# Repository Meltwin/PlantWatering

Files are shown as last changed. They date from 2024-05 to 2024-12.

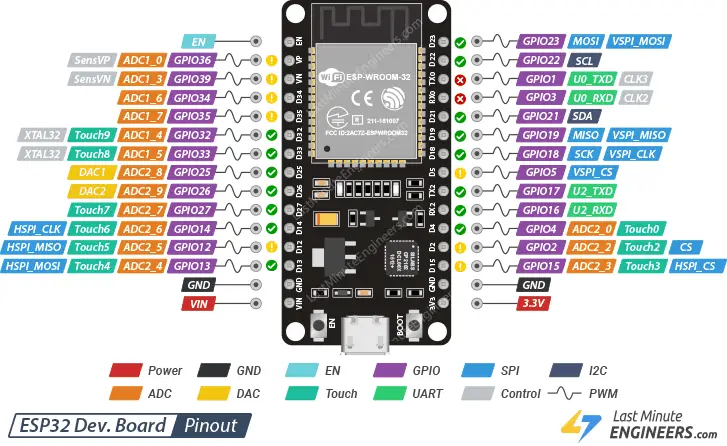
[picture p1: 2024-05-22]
img/esp-wroom-32-pinout.png

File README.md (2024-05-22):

<h1 align="center">
    Automatic plant watering system
</h1>

This project consist of making an automated watering system for my plants. It works with an ESP-32 board that controls a 5V pump. This repository contains:

- The electrical schematic (made in KiCAD) that can be found in the `KiCAD` folder,
- The code for the ESP-32 board in the `plant_watering` folder,

The project was tested and made on a ESP-WROOM-32 board.

Distributed under the MIT licence. Copyright (c) 2024 Meltwin

## Hardware description

The parts used here are:

- an ESP32 board,
- a dual MOFSET driver,
- USB-C female port for power input,
- Barrel Jack female port for power output (for the pump)

## Software description

The software available here control a 5V pump through the dual MOSFET driver with a PWM signal. There two main parameter for controlling the pump behaviour: the **opened time** and the **opened frequency**. This way people can freely choose the quantity of water to actually drop according to the type of plant.

This data will be stored onto the ESP controller internal storage so that it survive power disconnect.

## Online resources used

- [ESP-32 Getting Started - Expressif](https://docs.espressif.com/projects/esp-idf/en/stable/esp32/hw-reference/esp32/get-started-devkitc.html)
- [ESP-32 Pinout - Last Minute Engineers](https://lastminuteengineers.com/esp32-pinout-reference/)
- [PWN usage - Upesy (FR only)](https://www.upesy.fr/blogs/tutorials/how-to-use-pwm-on-esp32-with-examples)
- [ADC usage - Last Minute Engineers](https://lastminuteengineers.com/esp32-basics-adc/)

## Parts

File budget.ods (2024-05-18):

Item | N | Link | Price | N Units | Price / U |  | Option 1 (DE) |  |  | Option 2 (US) |  |  | Option 3 (DE + US) |  |  | Option 1
 |  |  |  |  |  |  |  |  |  |  |  |  |  |  |  | Total | Needed
5V Pump | 1 | Amazon DE (https://www.amazon.de/-/en/RUNCCI-YUN-Submersible-Aquarium-Watering-Flowers/dp/B08BZBN29C) | 9,44 € | 3 | 3,15 € | 1 | X | 3,15 € | 9,44 € |  | 0,00 € | 0,00 € |  | 0,00 € | 0,00 € | 63,80 € | 9,75 € | 15,29 %
5V Pump | 1 | Amazon DE (https://www.amazon.de/-/en/gp/product/B0B24G8WP7) | 8,39 € | 1 | 8,39 € | 1 |  | 0,00 € | 0,00 € |  | 0,00 € | 0,00 € |  | 0,00 € | 0,00 €
5V Pump | 1 | Amazon US (https://www.amazon.com/ALAMSCN-Submersible-Aquariums-Fountain-Hydroponics/dp/B08PBQ1N1G?rnid=2661617011) | $9,99 | 4 | $2,50 | 0,93 |  | 0,00 € | 0,00 € | X | 2,32 € | 9,29 € | X | 2,32 € | 9,29 €
Mosfet drivers | 1 | Amazon DE (https://www.amazon.de/-/en/Trigger-Setting-Electronic-Control-Arduino/dp/B0C3LXNK7T) | 11,99 € | 20 | 0,60 € | 1 | X | 0,60 € | 11,99 € |  | 0,00 € | 0,00 € |  | 0,00 € | 0,00 € | Option 2
H Bridge | 1 | Amazon DE (https://www.amazon.de/-/en/ARCELI-Pieces-Controller-Module-Arduino/dp/B07MY33PC9/) | 13,65 € | 5 | 2,73 € | 1 |  | 0,00 € | 0,00 € |  | 0,00 € | 0,00 € |  | 0,00 € | 0,00 € | Total | Needed
Mosfet drivers | 1 | Amazon US (https://www.amazon.com/XLX-Transistor-Module-PWM-Regulator-Electronic-Switch-Controller/dp/B07ZHC5M7H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) | $11,99 | 10 | $1,20 | 0,93 |  | 0,00 € | 0,00 € | X | 1,12 € | 11,15 € | X | 1,12 € | 11,15 € | 71,83 € | 8,69 € | 12,09 %
W Alu Heatsinks | 1 | Amazon DE (https://www.amazon.de/-/en/VooGenzek-Aluminium-Raspberry-Heatsink-Conducting/dp/B0C2HW56YJ?rnid=419116031) | 6,91 € | 40 | 0,17 € | 1 | X | 0,17 € | 6,91 € |  | 0,00 € | 0,00 € | X | 0,17 € | 6,91 €
Kit Alu Heatsinks | 1 | Amazon DE (https://www.amazon.de/-/en/Different-Heatsink-Conductive-Aluminium-Raspberry/dp/B099J1W63H) | 19,95 € | 102 | 0,20 € | 1 |  | 0,00 € | 0,00 € |  | 0,00 € | 0,00 € |  | 0,00 € | 0,00 € | Option 3
Kit Alu Heatsinks | 1 | Amazon US (https://www.amazon.com/GeeekPi-Conductive-Raspberry-Transistor-Regulator/dp/B099DTH24X) | $15,99 | 100 | $0,16 | 0,93 |  | 0,00 € | 0,00 € |  | 0,00 € | 0,00 € |  | 0,00 € | 0,00 € | Total | Needed
Kit Alu Heatsinks | 1 | Amazon US (https://www.amazon.com/Raspberry-Heatsink-Conductive-Adhesive-Aluminum/dp/B082RWXFR2) | $12,99 | 100 | $0,13 | 0,93 |  | 0,00 € | 0,00 € |  | 0,00 € | 0,00 € |  | 0,00 € | 0,00 € | 66,93 € | 8,76 € | 13,09 %
Kit Alu Heatsinks | 1 | Amazon US (https://www.amazon.com/Raspberry-Heatsink-MazerPi-Aluminum-Thermal/dp/B0963BMGFY) | $11,99 | 100 | $0,12 | 0,93 |  | 0,00 € | 0,00 € | X | 0,11 € | 11,15 € |  | 0,00 € | 0,00 €
Heatshrink tubes | 6 | Amazon DE (https://www.amazon.de/-/en/ASHINER-Heat-Shrink-Tube-Set/dp/B08XXGNJHG) | 10,49 € | 580 | 0,02 € | 1 | X | 0,11 € | 10,49 € |  | 0,00 € | 0,00 € |  | 0,00 € | 0,00 €
Heatshrink tubes | 6 | Amazon US (https://www.amazon.com/560PCS-Heat-Shrink-Tubing-Eventronic/dp/B072PCQ2LW) | $6,99 | 560 | $0,01 | 0,93 |  | 0,00 € | 0,00 € | X | 0,07 € | 6,50 € | X | 0,07 € | 6,50 € | EUR coef | 1 | EUR/EUR
ESP32 | 1 | Amazon US (https://www.amazon.com/DORHEA-Development-Bluetooth-ESP-WROOM-32-ESP32-DevKitC-32/dp/B0B18NK2MS) | $26,99 | 5 | $5,40 | 0,93 |  | 0,00 € | 0,00 € | X | 5,02 € | 25,10 € | X | 5,02 € | 25,10 € | USD coef | 0,93 | EUR/USD
ESP32 | 1 | Amazon DE (https://www.amazon.de/-/en/pieces-ESP32-development-NodeMCU-modules/dp/B0CF9HF3PG) | 16,99 € | 3 | 5,66 € | 1 | X | 5,66 € | 16,99 € |  | 0,00 € | 0,00 € |  | 0,00 € | 0,00 €
 |  |  | 0,00 € | 1 | 0,00 € | 1 |  | 0,00 € | 0,00 € |  | 0,00 € | 0,00 € |  | 0,00 € | 0,00 €
Self-Taping screws | 4 | Amazon US (https://www.amazon.com/HanTof-Phillips-Computer-Self-Tapping-Electronic/dp/B07ZH9GJWP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) | $9,29 | 750 | $0,01 | 0,93 |  | 0,00 € | 0,00 € | X | 0,05 € | 8,64 € |  | 0,00 € | 0,00 €
Self-Taping screws | 4 | Amazon DE (https://www.amazon.de/-/en/VooGenzek-Self-Tapping-Tapping-Phillips-Plastic/dp/B09NDPGJG1?rnid=419116031) | 7,98 € | 500 | 0,02 € | 1 | X | 0,06 € | 7,98 € |  | 0,00 € | 0,00 € | X | 0,06 € | 7,98 €
 |  |  | 0,00 € | 1 | 0,00 € | 1 |  | 0,00 € | 0,00 € |  | 0,00 € | 0,00 € |  | 0,00 € | 0,00 €
 |  |  | 0,00 € | 1 | 0,00 € | 1 |  | 0,00 € | 0,00 € |  | 0,00 € | 0,00 € |  | 0,00 € | 0,00 €
 |  |  | 0,00 € | 1 | 0,00 € | 1 |  | 0,00 € | 0,00 € |  | 0,00 € | 0,00 € |  | 0,00 € | 0,00 €
 |  |  | 0,00 € | 1 | 0,00 € | 1 |  | 0,00 € | 0,00 € |  | 0,00 € | 0,00 € |  | 0,00 € | 0,00 €
 |  |  | 0,00 € | 1 | 0,00 € | 1 |  | 0,00 € | 0,00 € |  | 0,00 € | 0,00 € |  | 0,00 € | 0,00 €
 |  |  | 0,00 € | 1 | 0,00 € | 1 |  | 0,00 € | 0,00 € |  | 0,00 € | 0,00 € |  | 0,00 € | 0,00 €
 |  |  | 0,00 € | 1 | 0,00 € | 1 |  | 0,00 € | 0,00 € |  | 0,00 € | 0,00 € |  | 0,00 € | 0,00 €
 |  |  | 0,00 € | 1 | 0,00 € | 1 |  | 0,00 € | 0,00 € |  | 0,00 € | 0,00 € |  | 0,00 € | 0,00 €
 |  |  | 0,00 € | 1 | 0,00 € | 1 |  | 0,00 € | 0,00 € |  | 0,00 € | 0,00 € |  | 0,00 € | 0,00 €
 |  |  | 0,00 € | 1 | 0,00 € | 1 |  | 0,00 € | 0,00 € |  | 0,00 € | 0,00 € |  | 0,00 € | 0,00 €
 |  |  | 0,00 € | 1 | 0,00 € | 1 |  | 0,00 € | 0,00 € |  | 0,00 € | 0,00 € |  | 0,00 € | 0,00 €
 |  |  | 0,00 € | 1 | 0,00 € | 1 |  | 0,00 € | 0,00 € |  | 0,00 € | 0,00 € |  | 0,00 € | 0,00 €
 |  |  | 0,00 € | 1 | 0,00 € | 1 |  | 0,00 € | 0,00 € |  | 0,00 € | 0,00 € |  | 0,00 € | 0,00 €
 |  |  | 0,00 € | 1 | 0,00 € | 1 |  | 0,00 € | 0,00 € |  | 0,00 € | 0,00 € |  | 0,00 € | 0,00 €
 |  |  | 0,00 € | 1 | 0,00 € | 1 |  | 0,00 € | 0,00 € |  | 0,00 € | 0,00 € |  | 0,00 € | 0,00 €
 |  |  | 0,00 € | 1 | 0,00 € | 1 |  | 0,00 € | 0,00 € |  | 0,00 € | 0,00 € |  | 0,00 € | 0,00 €
 |  |  | 0,00 € | 1 | 0,00 € | 1 |  | 0,00 € | 0,00 € |  | 0,00 € | 0,00 € |  | 0,00 € | 0,00 €
 |  |  | 0,00 € | 1 | 0,00 € | 1 |  | 0,00 € | 0,00 € |  | 0,00 € | 0,00 € |  | 0,00 € | 0,00 €
 |  |  | 0,00 € | 1 | 0,00 € | 1 |  | 0,00 € | 0,00 € |  | 0,00 € | 0,00 € |  | 0,00 € | 0,00 €
 |  |  | 0,00 € | 1 | 0,00 € | 1 |  | 0,00 € | 0,00 € |  | 0,00 € | 0,00 € |  | 0,00 € | 0,00 €
 |  |  | 0,00 € | 1 | 0,00 € | 1 |  | 0,00 € | 0,00 € |  | 0,00 € | 0,00 € |  | 0,00 € | 0,00 €
 |  |  | 0,00 € | 1 | 0,00 € | 1 |  | 0,00 € | 0,00 € |  | 0,00 € | 0,00 € |  | 0,00 € | 0,00 €
 |  |  | 0,00 € | 1 | 0,00 € | 1 |  | 0,00 € | 0,00 € |  | 0,00 € | 0,00 € |  | 0,00 € | 0,00 €
 |  |  | 0,00 € | 1 | 0,00 € | 1 |  | 0,00 € | 0,00 € |  | 0,00 € | 0,00 € |  | 0,00 € | 0,00 €
 |  |  | 0,00 € | 1 | 0,00 € | 1 |  | 0,00 € | 0,00 € |  | 0,00 € | 0,00 € |  | 0,00 € | 0,00 €
 |  |  | 0,00 € | 1 | 0,00 € | 1 |  | 0,00 € | 0,00 € |  | 0,00 € | 0,00 € |  | 0,00 € | 0,00 €
 |  |  | 0,00 € | 1 | 0,00 € | 1 |  | 0,00 € | 0,00 € |  | 0,00 € | 0,00 € |  | 0,00 € | 0,00 €

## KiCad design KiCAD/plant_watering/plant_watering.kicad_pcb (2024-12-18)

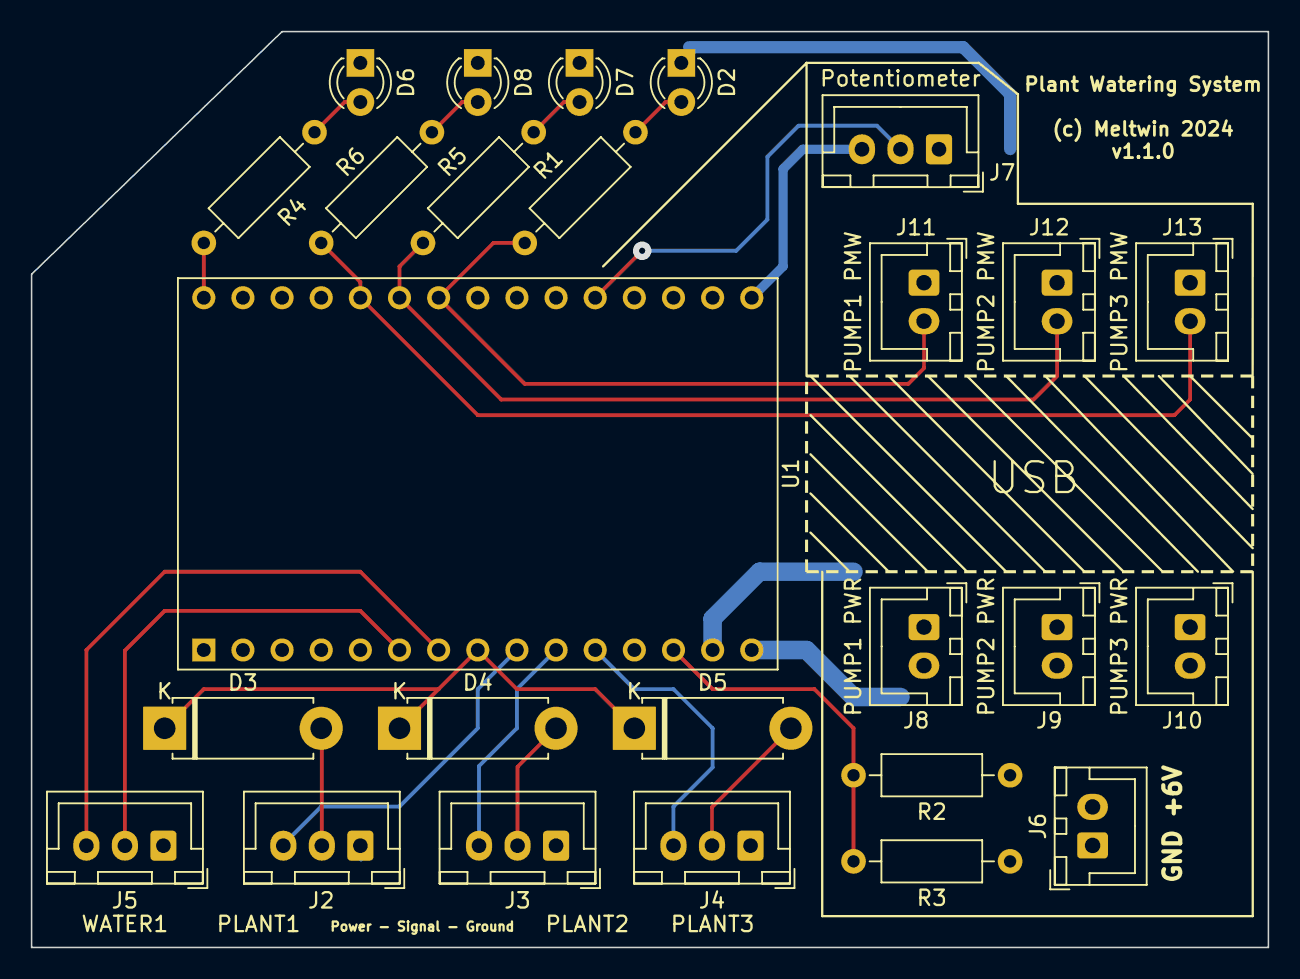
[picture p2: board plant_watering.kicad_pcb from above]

Board: 2 copper layers, 80.3 x 59.4 mm, 26 parts (0 on the bottom side), 22 nets.

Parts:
D2, D6, D7, D8: LED; LED_D3.0mm
D3, D4, D5: D; D_5W_P10.16mm_Horizontal
J2: PLANT1; JST_XH_B3B-XH-A_1x03_P2.50mm_Vertical
J3: PLANT2; JST_XH_B3B-XH-A_1x03_P2.50mm_Vertical
J4: PLANT3; JST_XH_B3B-XH-A_1x03_P2.50mm_Vertical
J5: WATER1; JST_XH_B3B-XH-A_1x03_P2.50mm_Vertical
J6: 4xLR6 1.5V Battery Pack; JST_XH_B2B-XH-A_1x02_P2.50mm_Vertical
J7: Potentiometer; JST_XH_B3B-XH-A_1x03_P2.50mm_Vertical
J8: PUMP1 PWR; JST_XH_B2B-XH-A_1x02_P2.50mm_Vertical
J9: PUMP2 PWR; JST_XH_B2B-XH-A_1x02_P2.50mm_Vertical
J10: PUMP3 PWR; JST_XH_B2B-XH-A_1x02_P2.50mm_Vertical
J11: PUMP1 PMW; JST_XH_B2B-XH-A_1x02_P2.50mm_Vertical
J12: PUMP2 PMW; JST_XH_B2B-XH-A_1x02_P2.50mm_Vertical
J13: PUMP3 PMW; JST_XH_B2B-XH-A_1x02_P2.50mm_Vertical
R1, R4, R5, R6: 220Ω; R_Axial_DIN0207_L6.3mm_D2.5mm_P10.16mm_Horizontal
R2: R_Battery; R_Axial_DIN0207_L6.3mm_D2.5mm_P10.16mm_Horizontal
R3: R_battery; R_Axial_DIN0207_L6.3mm_D2.5mm_P10.16mm_Horizontal
U1: ESP32-WROOM-32; ESP32-C3-DevKitM-1

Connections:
+3V3: J7.3, U1.3V3 (VDD_3V)
+6V: J6.2, J8.2, J9.2, J10.2, R2.1, U1.VIN (VDD_5V)
/BAT_LVL_3V: R2.2, R3.2, U1.D13 (IO13/ADC2_4/HSPI_MOSI/Touch4)
/MANUAL_PWM: J7.2, U1.D4 (IO4/ADC2_0/Touch0)
/PLANT1_ENB: J2.3, U1.D26 (IO26/ADC2_9/DAC2)
/PLANT1_SIG: D3.2 (A), J2.2
/PLANT2_ENB: J3.3, U1.D27 (IO27/ADC2_7/Touch7)
/PLANT2_SIG: D4.2 (A), J3.2
/PLANT3_ENB: J4.3, U1.D14 (IO14/ADC2_6/HSPI_CLK/Touch6)
/PLANT3_SIG: D5.2 (A), J4.2
/PUMP1_PWM: J11.2, R1.1, U1.D18 (IO18/SPI_SCK/VSPI_SLK)
/PUMP2_PWM: J12.2, R5.1, U1.D19 (IO19/MISO/VSPI_MISO)
/PUMP3_PWM: J13.2, R6.1, U1.D21 (IO21/SDA)
/STATUS: R4.1, U1.D23 (IO23/SPI_MOSI/VSPI_MOSI)
/WATER_LEVEL_ENB: J5.3, U1.D33 (IO33/ADC1_5/Touch8)
/WATER_LEVEL_SIG: J5.2, U1.D32 (IO32/ADC1_4/Touch9)
GND: D2.1 (K), D6.1 (K), D7.1 (K), D8.1 (K), J2.1, J3.1, J4.1, J5.1, J6.1, J7.1, J8.1, J9.1, J10.1, J11.1, J12.1, J13.1, R3.1, U1.GND
unnamed: D2.2 (A), R1.2
unnamed: D3.1 (K), D4.1 (K), D5.1 (K), U1.D25 (IO25/ADC2_8/DAC1)
unnamed: D6.2 (A), R4.2
unnamed: D7.2 (A), R5.2
unnamed: D8.2 (A), R6.2

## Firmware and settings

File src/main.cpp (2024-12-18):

/**
 *  ===========================================================================
 *                      Automated Plant Watering System
 *                     By Meltwin - 2024 (c) MIT Licence
 *  ============================================================================
 */

#include <Arduino.h>
#include "ApiCaller.hpp"
#include "IO/Pump.hpp"
#include "IO/Sensor.hpp"
#include "WifiConnect.hpp"
#include "common.hpp"

#include "datetime.h"
#include "dev_console.h"

// ----------------------------------------------------------------------------
// Parameters
// ----------------------------------------------------------------------------
#define WIFI_SSID "B-DTU Wireless"
#define WIFI_PSW "StudentDK"

// Sensors
#define BATTERY_SENSOR_DATA GPIO_NUM_13
#define PLANT1_SENSOR_ENABLE GPIO_NUM_26
#define PLANT2_SENSOR_ENABLE GPIO_NUM_27
#define PLANT3_SENSOR_ENABLE GPIO_NUM_14
#define PLANTS_SENSOR_DATA GPIO_NUM_25
#define WATER_LEVEL_ENABLE GPIO_NUM_33
#define WATER_LEVEL_DATA GPIO_NUM_32

// Pump
#define PUMP1_PWM_PIN GPIO_NUM_18
#define PUMP2_PWM_PIN GPIO_NUM_19
#define PUMP3_PWM_PIN GPIO_NUM_21
#define PUMP_PWM_CHANNEL 0
#define PUMP_PWM_FREQ 16000
#define PUMP_PWM_RESOLUTION 12

// ----------------------------------------------------------------------------
// Aliases
// ----------------------------------------------------------------------------
using meltwin::APICaller;
using meltwin::InternalErrors;
using meltwin::Pump;
using meltwin::PumpCmd;
using meltwin::Sensor;


bool console = false;

// ----------------------------------------------------------------------------
// Debug Console & Automatic Watering programs
// ----------------------------------------------------------------------------
void run_console() {
  do
    Serial.println("Waiting for next cmd ...");
  while (!meltwin::DevConsole::execute_command());
}

void run_watering() {
  // ============================================
  // I - Reading sensors
  // ============================================
  std::vector<Sensor> sensors{
    Sensor(BATTERY_SENSOR_DATA, 0.0, 6.0),
    Sensor(PLANTS_SENSOR_DATA, 0.0, 1.0, PLANT1_SENSOR_ENABLE),
    Sensor(PLANTS_SENSOR_DATA, 0.0, 1.0, PLANT2_SENSOR_ENABLE),
    Sensor(PLANTS_SENSOR_DATA, 0.0, 1.0, PLANT3_SENSOR_ENABLE),
    Sensor(WATER_LEVEL_DATA, 0.0, 1.0, WATER_LEVEL_ENABLE),
  };
  float values[sensors.size()];
  Serial.println("Reading sensors values");
  for (size_t i = 0; i < sensors.size(); i++) {
    Serial.printf("\t-> Reading sensor %zu ... ", i);
    auto& s = sensors[i];
    s.setup_sensor();
    values[i] = s.read_sensor();
    Serial.printf("%f\n", values[i]);
    s.cleanup();
  }

  // ============================================
  // II - Connect to API
  // ============================================
  Serial.println("Initializing WiFi");
  if (!init_wifi(WIFI_SSID, WIFI_PSW))
    return;

  Serial.println("Authenticating on the API");
  std::string token;
  if (auto code = APICaller::authenticate(token); code != InternalErrors::SUCCESS) {
    Serial.printf("\t-> Couldn't authenticate on API: error %d\n", code);
    return;
  }
  Serial.printf("\t-> The connction token is {%s}\n", token.c_str());

  // Upload sensors values
  Serial.println("Sending sensors data to the API");
  for (size_t i = 0; i < sensors.size(); i++) {
    Serial.printf("\t-> Sending data for sensor %zu\n", i);
    if (auto code = APICaller::sendData(token.c_str(), i, values[i]); code != InternalErrors::SUCCESS)
      Serial.printf("\t  Couldn't send sensor data on API: error %d\n", code);
  }

  // ============================================
  // III - Watering plants
  // ============================================
  std::vector<Pump> pumps{Pump(PUMP1_PWM_PIN, PUMP_PWM_CHANNEL, PUMP_PWM_RESOLUTION)};
  for (size_t i = 0; i < pumps.size(); i++) {
    auto& pump = pumps[i];
    PumpCmd cmd;
    APICaller::getPumpCmd(token.c_str(), i, cmd);

    // Power pump if needed
    if (cmd.time > 0.0 && cmd.pwm > 0.0) {
      Serial.printf("Running pump %zu for %f s at %f % ...\n", i, cmd.time, cmd.pwm);
      pump.setup_pump(PUMP_PWM_FREQ);
      pump.run_pump(cmd);
      pump.stop_pump();
    }
    APICaller::pumpingDone(token.c_str(), i);
  }
}

void wrap_up() {
  Serial.println("Wrapping up ...");

  delay(1000);
  digitalWrite(13, LOW);
  Serial.end();
  delay(1000);
  esp_sleep_enable_timer_wakeup(DEEP_SLEEP_DURATION);
  esp_deep_sleep_start();
}

// ----------------------------------------------------------------------------
// Setup
// ----------------------------------------------------------------------------
void setup() {

  // Setup sub classes
  Serial.begin(SERIAL_BAUD_RATE);

  // Setup deep sleep
  esp_sleep_enable_timer_wakeup(DEEP_SLEEP_DURATION);

  // Load activity pin
  pinMode(13, OUTPUT);
  digitalWrite(13, HIGH);

  // // Look for serial connection for preferences dev console
  Serial.printf("Send \"cmd\" to start developer console (%f s)\n", meltwin::DevConsole::START_TIMEOUT / 1000.);
  console = meltwin::DevConsole::wait_for_console_launch();

  (console) ? run_console() : run_watering();
  wrap_up();
}

void loop() {}

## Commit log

2024-05-18 Beginning of electrical schematic
    [budget.ods, plant_watering.kicad_pcb, plant_watering.kicad_sch]
2024-05-18 Base ESP32 script
    [plant_watering.kicad_sch]
2024-05-22 PWM working + Manual input working as well
    [plant_watering.kicad_sch]
2024-12-18 API Exchange
    [plant_watering.kicad_pcb, plant_watering.kicad_sch]
